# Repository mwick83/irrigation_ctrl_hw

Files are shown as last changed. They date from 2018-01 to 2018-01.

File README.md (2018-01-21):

# Irrigation Controller (hardware repo)

This is the hardware repository for the Irrigation Controller project. The repository holding the software of the project contains the documentation. Please refer to [https://github.com/mwick83/irrigation_ctrl](https://github.com/mwick83/irrigation_ctrl).

## License

Copyright (c) 2017-2018 Manuel Wick

Licensed under the BSD 3-clause "New" or "Revised" License.
See LICENSE.md file or [http://www.opensource.org/licenses/BSD-3-Clause](http://www.opensource.org/licenses/BSD-3-Clause) for details.

## Archived footprints

Please note that most of the footprints in directories "archived_footprints.pretty" are derived from the KiCAD distribution. They are licensed under their own associated license. These footprints are only provided for convenience and archiving purposes.

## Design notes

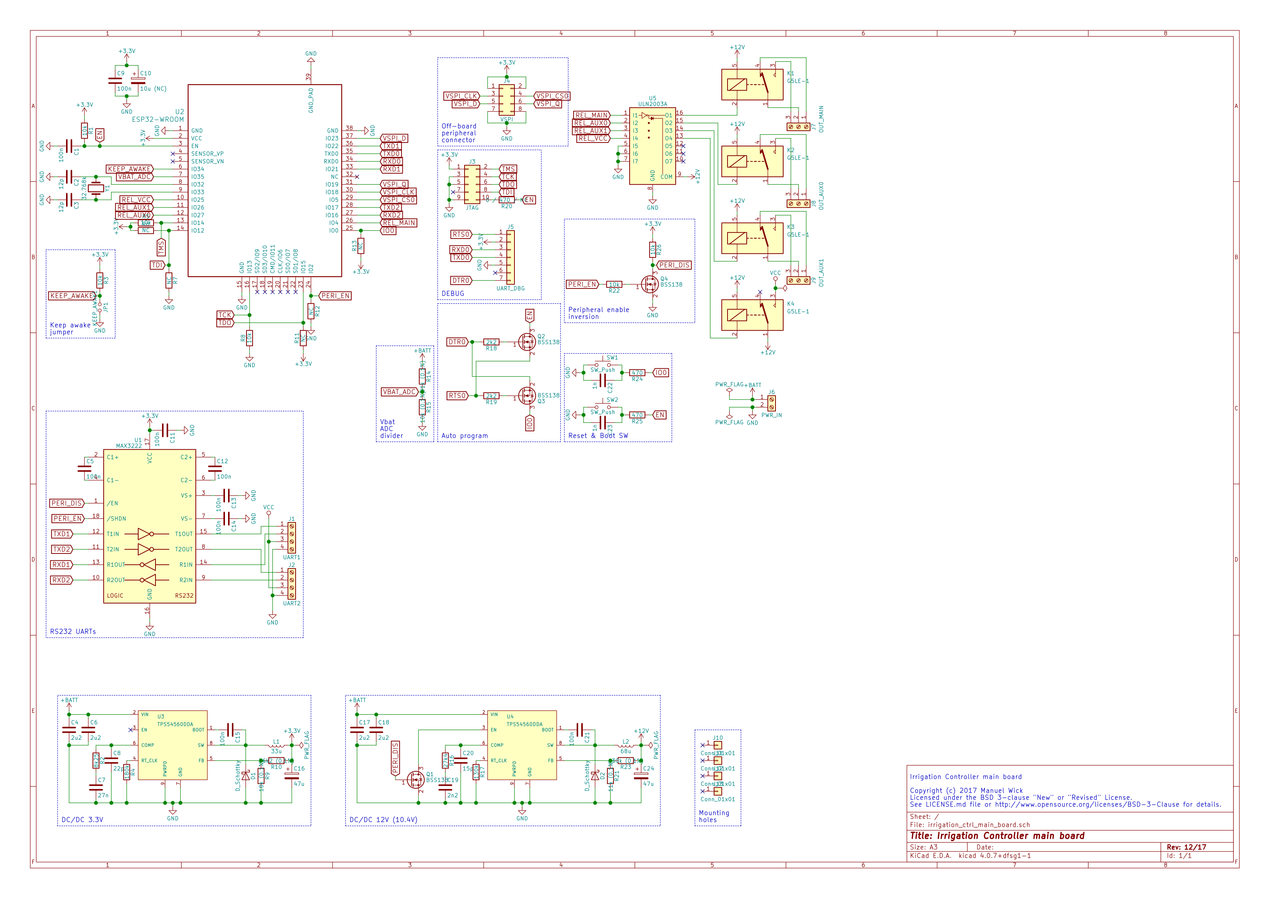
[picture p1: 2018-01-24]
main_board/irrigation_ctrl_main_board_1217_schem.png

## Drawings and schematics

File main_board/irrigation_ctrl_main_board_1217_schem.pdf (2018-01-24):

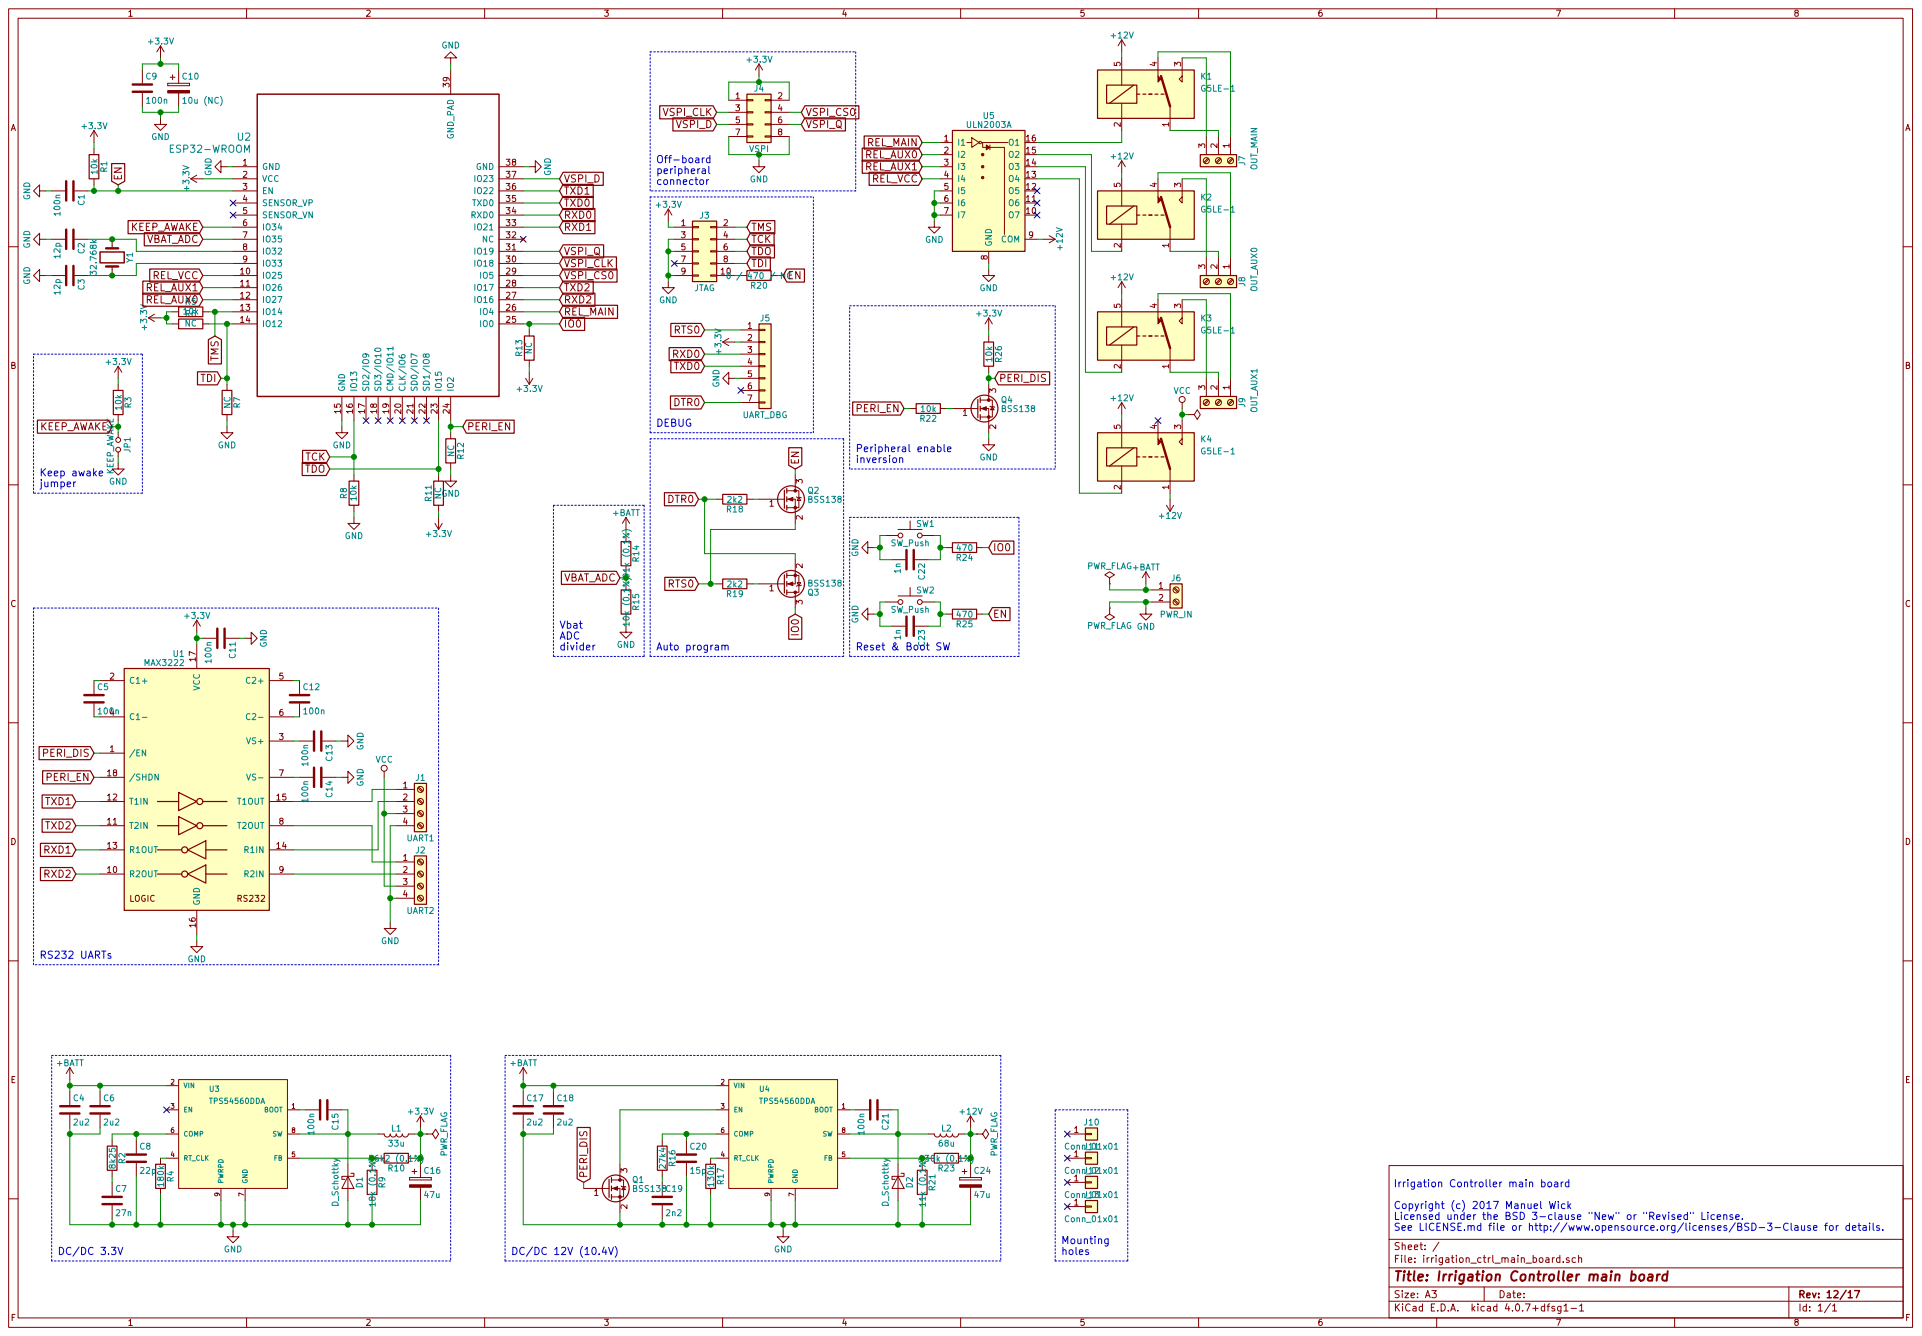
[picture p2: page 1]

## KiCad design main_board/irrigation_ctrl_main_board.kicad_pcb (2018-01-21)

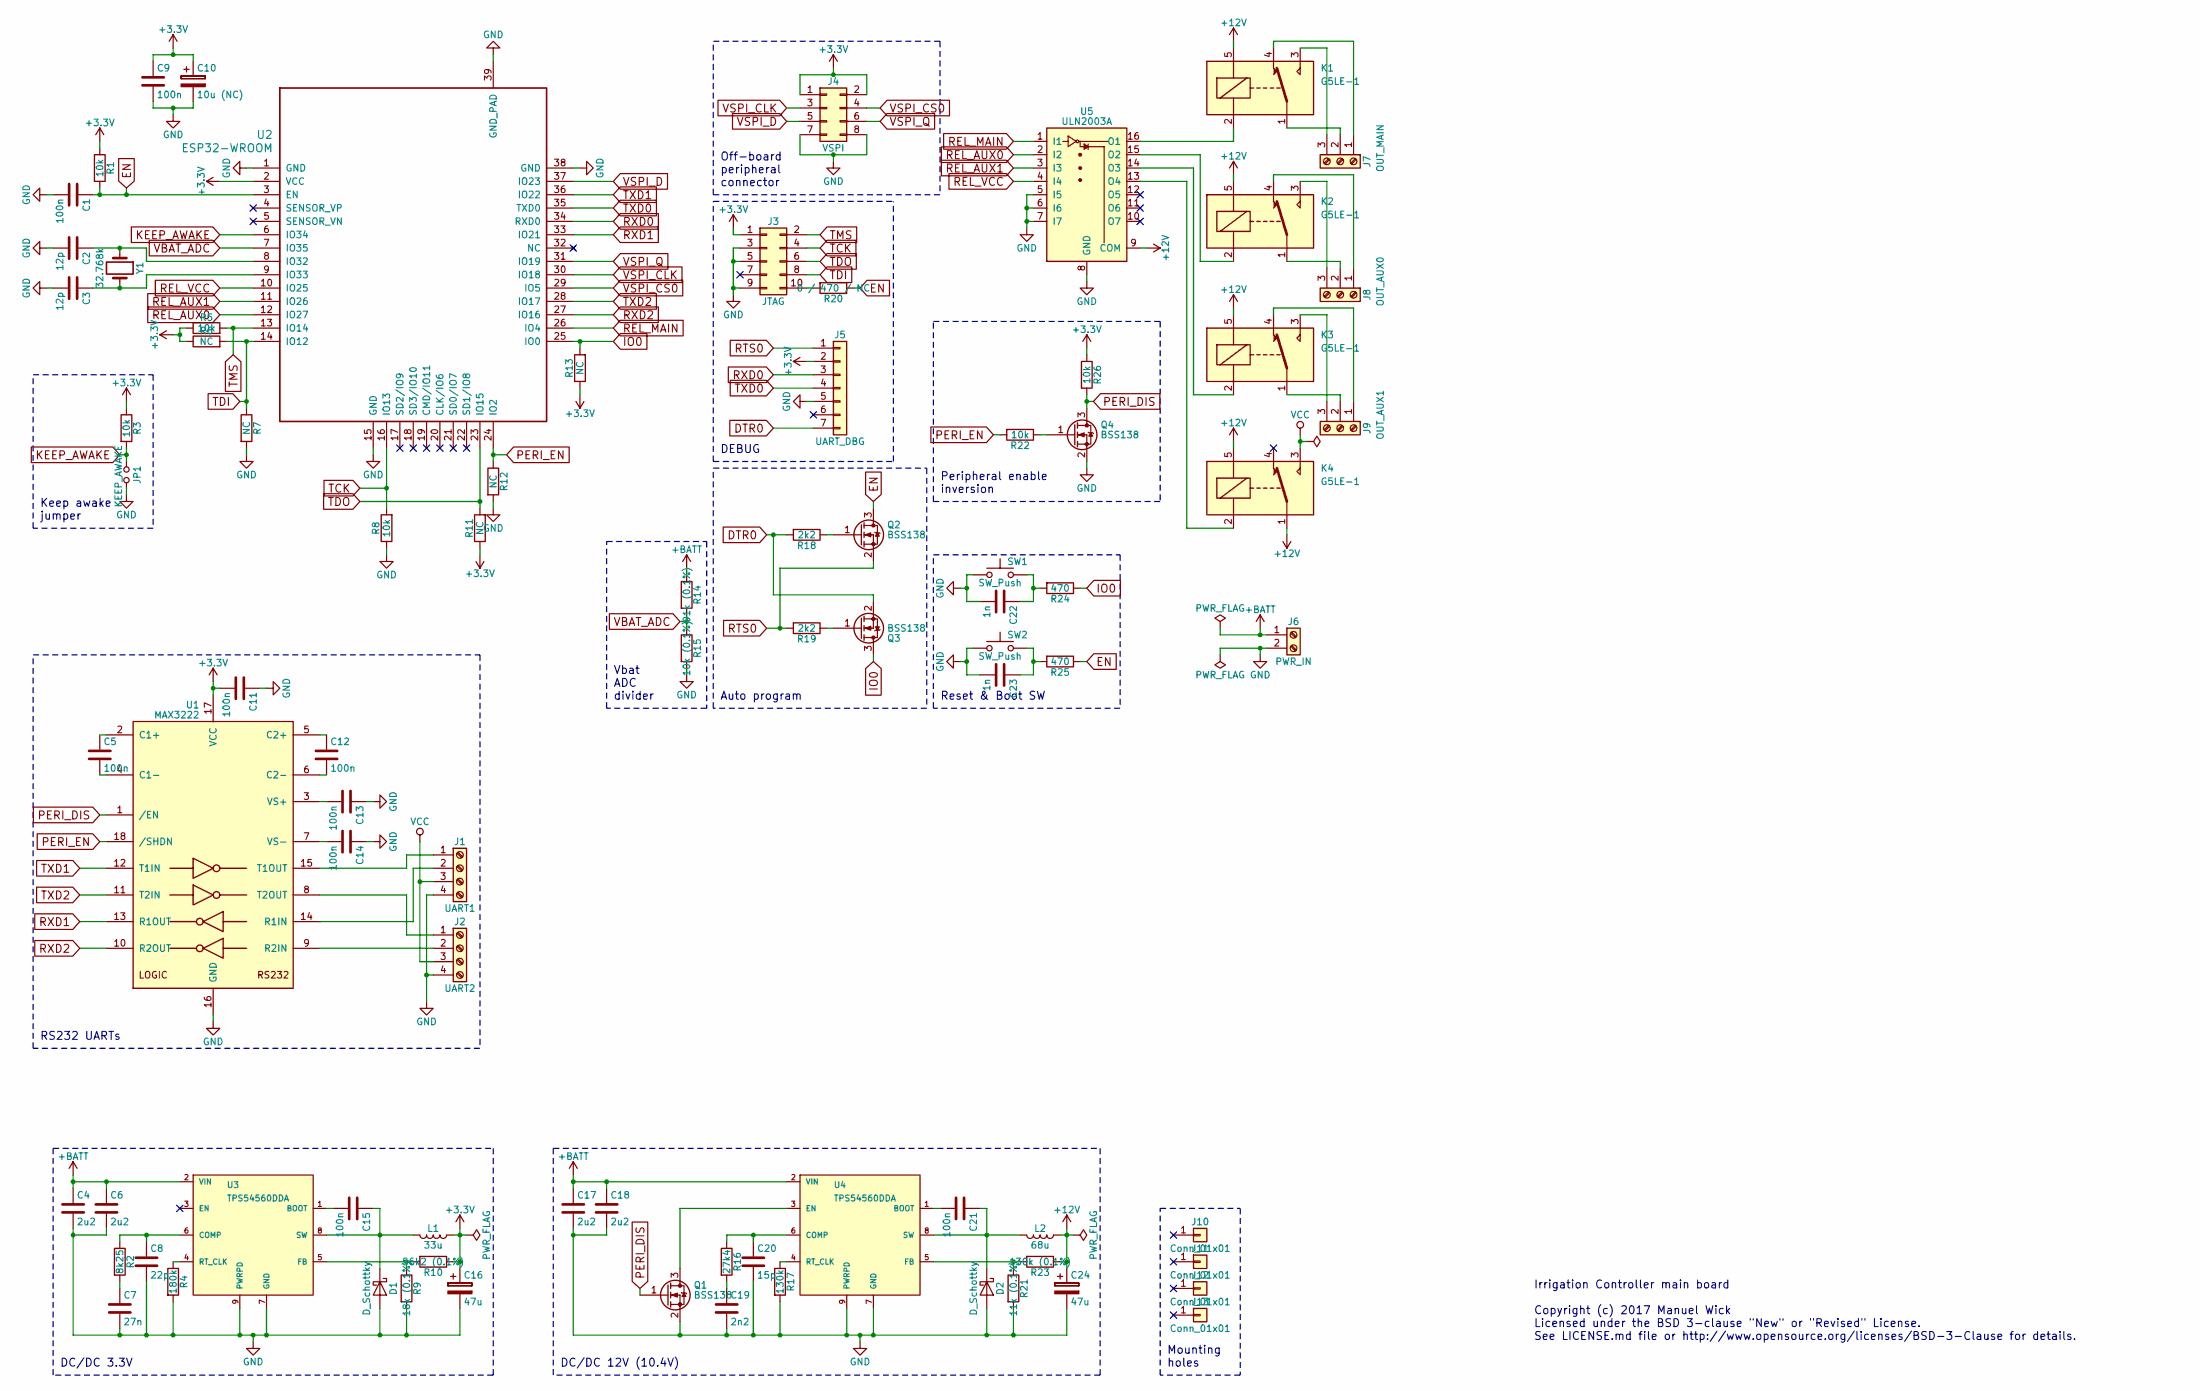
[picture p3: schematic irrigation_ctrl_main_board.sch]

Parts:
C1, C5, C9, C11, C12, C13, C14, C15, C21: 100n; C_0805_HandSoldering
C2, C3: 12p; C_0805_HandSoldering
C4, C6, C17, C18: 2u2; C_1206_HandSoldering
C7: 27n; C_0805_HandSoldering
C8: 22p; C_0805_HandSoldering
C10: 10u (NC); C_1206_HandSoldering
C16, C24: 47u; CP_Elec_8x6.7
C19: 2n2; C_0805_HandSoldering
C20: 15p; C_0805_HandSoldering
C22, C23: 1n; C_0805_HandSoldering
D1, D2: D_Schottky; D_SMC_Handsoldering
J1: UART1; AKL230-04
J2: UART2; AKL230-04
J3: JTAG; IDC_Header_Straight_10pins_005
J4: VSPI; Pin_Header_Straight_2x04_Pitch2.54mm
J5: UART_DBG; Pin_Header_Straight_1x07_Pitch2.54mm
J6: PWR_IN; AKL230-02
J7: OUT_MAIN; AKL230-03
J8: OUT_AUX0; AKL230-03
J9: OUT_AUX1; AKL230-03
J10, J11, J12, J13: Conn_01x01; MountingHole_3.2mm_M3
JP1: KEEP_AWAKE; Pin_Header_Straight_1x02_Pitch2.54mm
K1, K2, K3, K4: G5LE-1; Relay_SPDT_OMRON-G5LE-1
L1: 33u; L_7.3x7.3_H4.5
L2: 68u; L_7.3x7.3_H4.5
Q1, Q2, Q3, Q4: BSS138; SOT-23
R1, R3, R5, R8, R22, R26: 10k; R_0805_HandSoldering
R2: 8k25; R_0805_HandSoldering
R4: 180k; R_0805_HandSoldering
R6, R7, R11, R12, R13: NC; R_0805_HandSoldering
R9: 18k (0.1%); R_0805_HandSoldering
R10: 56k2 (0.1%); R_0805_HandSoldering
R14: 91k (0.1%); R_0805_HandSoldering
R15: 10k (0.1%); R_0805_HandSoldering
R16: 27k4; R_0805_HandSoldering
R17: 130k; R_0805_HandSoldering
R18, R19: 2k2; R_0805_HandSoldering
R20: 0 / 470 / NC; R_0805_HandSoldering
R21: 11k (0.1%); R_0805_HandSoldering
R23: 130k (0.1%); R_0805_HandSoldering
R24, R25: 470; R_0805_HandSoldering
SW1, SW2: SW_Push; SW_SPST_REICHELT_SMD
U1: MAX3222; SOIC-18W_7.5x11.6mm_Pitch1.27mm
U2: ESP32-WROOM
U3, U4: TPS54560DDA; TI_SO-PowerPAD-8
U5: ULN2003A; SOIC-16_3.9x9.9mm_Pitch1.27mm
Y1: 32.768k; Crystal_DS26_d2.0mm_l6.0mm_Horizontal

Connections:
+3V3: C9.1, C10.1, C11.2, C16.1, J3.1, J4.1, J4.2, J5.2, L1.1, R1.1, R3.1, R5.1, R6.1, R10.1, R11.1, R13.1, R26.1, U1.17 (VCC), U2.2 (VCC)
+12V: C24.1, K1.5, K2.5, K3.5, K4.1, K4.5, L2.1, R23.1, U5.9 (COM)
+BATT: C4.1, C6.1, C17.1, C18.1, J6.1, R14.1, U3.2 (VIN), U4.2 (VIN)
DTR0: J5.7, Q3.2 (S), R18.2
EN: C1.1, Q2.3 (D), R1.2, R20.1, R25.1, U2.3 (EN)
GND: C1.2, C2.2, C3.2, C4.2, C6.2, C7.2, C8.2, C9.2, C10.2, C11.1, C13.1, C14.1, C16.2, C17.2, C18.2, C19.2, C20.2, C22.2, C23.2, C24.2, D1.2 (A), D2.2 (A), J1.4, J2.4, J3.3, J3.5, J3.9, J4.7, J4.8, J5.5, J6.2, JP1.2, Q1.2 (S), Q4.2 (S), R4.2, R7.2, R8.1, R9.2, R12.2, R15.2, R17.2, R21.2, SW1.1, SW2.1, U1.16 (GND), U2.1 (GND), U2.15 (GND), U2.38 (GND), U2.39 (GND_PAD), U3.7 (GND), U3.9 (PWRPD), U4.7 (GND), U4.9 (PWRPD), U5.5 (I5), U5.6 (I6), U5.7 (I7), U5.8 (GND)
IO0: Q3.3 (D), R13.2, R24.1, U2.25 (IO0)
KEEP_AWAKE: JP1.1, R3.2, U2.6 (IO34)
unnamed: C2.1, U2.8 (IO32), Y1.1
unnamed: C3.1, U2.9 (IO33), Y1.2
unnamed: C5.1, U1.2 (C1+)
unnamed: C5.2, U1.4 (C1-)
unnamed: C7.1, R2.2
unnamed: C8.1, R2.1, U3.6 (COMP)
unnamed: C12.1, U1.5 (C2+)
unnamed: C12.2, U1.6 (C2-)
unnamed: C13.2, U1.3 (VS+)
unnamed: C14.2, U1.7 (VS-)
unnamed: C15.1, D1.1 (K), L1.2, U3.8 (SW)
unnamed: C15.2, U3.1 (BOOT)
unnamed: C19.1, R16.2
unnamed: C20.1, R16.1, U4.6 (COMP)
unnamed: C21.1, D2.1 (K), L2.2, U4.8 (SW)
unnamed: C21.2, U4.1 (BOOT)
unnamed: C22.1, R24.2, SW1.2
unnamed: C23.1, R25.2, SW2.2
unnamed: J1.1, U1.15 (T1OUT)
unnamed: J1.2, U1.14 (R1IN)
unnamed: J2.1, U1.8 (T2OUT)
unnamed: J2.2, U1.9 (R2IN)
unnamed: J3.10, R20.2
unnamed: J7.1, K1.4
unnamed: J7.2, K1.1
unnamed: J7.3, K1.3
unnamed: J8.1, K2.4
unnamed: J8.2, K2.1
unnamed: J8.3, K2.3
unnamed: J9.1, K3.4
unnamed: J9.2, K3.1
unnamed: J9.3, K3.3
unnamed: K1.2, U5.16 (O1)
unnamed: K2.2, U5.15 (O2)
unnamed: K3.2, U5.14 (O3)
unnamed: K4.2, U5.13 (O4)
unnamed: Q1.3 (D), U4.3 (EN)
unnamed: Q2.1 (G), R18.1
unnamed: Q3.1 (G), R19.1
unnamed: Q4.1 (G), R22.1
unnamed: R4.1, U3.4 (RT_CLK)
unnamed: R9.1, R10.2, U3.5 (FB)
unnamed: R17.1, U4.4 (RT_CLK)
unnamed: R21.1, R23.2, U4.5 (FB)
PERI_DIS: Q1.1 (G), Q4.3 (D), R26.2, U1.1 (/EN)
PERI_EN: R12.1, R22.2, U1.18 (/SHDN), U2.24 (IO2)
REL_AUX0: U2.12 (IO27), U5.2 (I2)
REL_AUX1: U2.11 (IO26), U5.3 (I3)
REL_MAIN: U2.26 (IO4), U5.1 (I1)
REL_VCC: U2.10 (IO25), U5.4 (I4)
RTS0: J5.1, Q2.2 (S), R19.2
RXD0: J5.3, U2.34 (RXD0)
RXD1: U1.13 (R1OUT), U2.33 (IO21)
RXD2: U1.10 (R2OUT), U2.27 (IO16)
TCK: J3.4, R8.2, U2.16 (IO13)
TDI: J3.8, R6.2, R7.1, U2.14 (IO12)
TDO: J3.6, R11.2, U2.23 (IO15)
TMS: J3.2, R5.2, U2.13 (IO14)
TXD0: J5.4, U2.35 (TXD0)
TXD1: U1.12 (T1IN), U2.36 (IO22)
TXD2: U1.11 (T2IN), U2.28 (IO17)
VBAT_ADC: R14.2, R15.1, U2.7 (IO35)
VCC: J1.3, J2.3, K4.3
VSPI_CLK: J4.3, U2.30 (IO18)
VSPI_CS0: J4.4, U2.29 (IO5)
VSPI_D: J4.5, U2.37 (IO23)
VSPI_Q: J4.6, U2.31 (IO19)

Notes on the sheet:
Auto program
Reset & Boot SW
Keep awake jumper
DEBUG
RS232 UARTs
Vbat ADC divider
Off-board peripheral connector
DC/DC 3.3V
DC/DC 12V (10.4V)
Peripheral enable inversion
Irrigation Controller main board Copyright (c) 2017 Manuel Wick Licensed under the BSD 3-clause "New" or "Revised" License. See LICENSE.md file or http://www.opensource.org/licenses/BSD-3-Clause for details.
Mounting holes

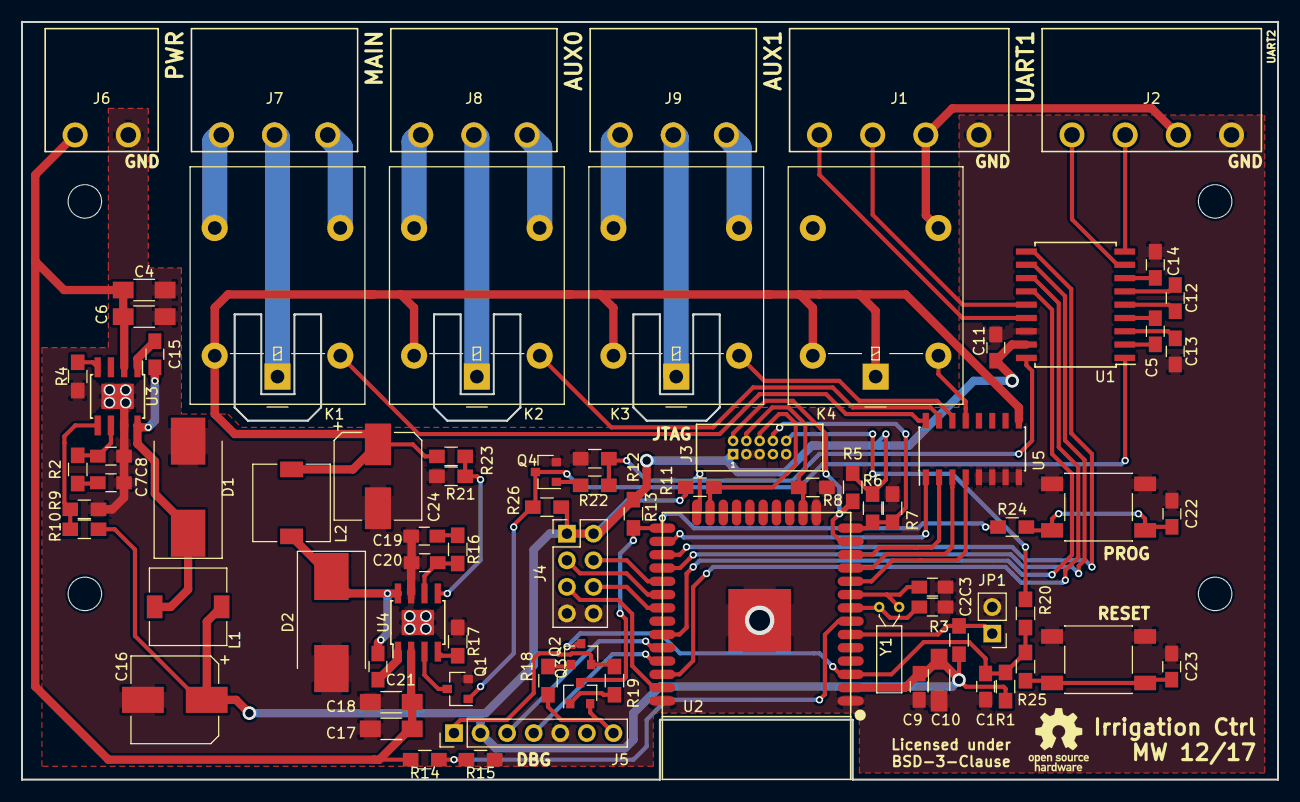
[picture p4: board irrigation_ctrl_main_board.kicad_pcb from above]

Board: 2 copper layers, 120.0 x 72.4 mm, 84 parts (0 on the bottom side), 75 nets.

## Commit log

2017-10-31 Add webench DCDC exproted files
    [2017-10-09_13-36-32.sch, 2017-10-09_13-37-02.brd, combined.sch]
2017-10-31 Add completed main board
    [irrigation_ctrl_main_board.kicad_pcb, irrigation_ctrl_main_board.sch]
2017-11-14 Update of manufactured state
    Moved notes of the schematic to the correct part. Updated XML file,
    which has been missed on manufactured checkin.
    [irrigation_ctrl_main_board.sch]
2017-11-14 Updated AKL footprints
    Changed footprints to match diameter recommended by manufacturer.
    [irrigation_ctrl_main_board.kicad_pcb]
2018-01-07 Removed temporary exported DCDC converter designs
    [2017-10-09_13-36-32.sch, 2017-10-09_13-37-02.brd, combined.sch]
2018-01-21 Preparations for publication
    [irrigation_ctrl_main_board.kicad_pcb, irrigation_ctrl_main_board.sch]
2018-01-24 Added exported schematics
    [irrigation_ctrl_main_board.sch]
